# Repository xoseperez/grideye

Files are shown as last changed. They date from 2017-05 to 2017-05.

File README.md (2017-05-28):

# GridEye Camera

This is a 8x8 pixels IR camera based on the **Panasonic AMG88XX GridEye** sensors.
It uses a **WS2812 8x8 matrix** as camera display, an **128x32 uOLED display** for data and
a **Moteino** board with an ATMega328P microcontroller as controller.
It is powered by a **LiPo battery** connected to a **TP4056 based LiPO charger**.
There is also a **Pololu Adjustable Boost Regulator 2.5-9.5V** to power the LED matrix.

The AMG8833 is an 8x8 IR sensor by Panasonic with an I2C interface that reports concact-less temperature values from -20 to 80 celsius with a 2.5C accuracy and 0.25C resolution. It has a field view of ~60º and a max detection distance of 5 meters.

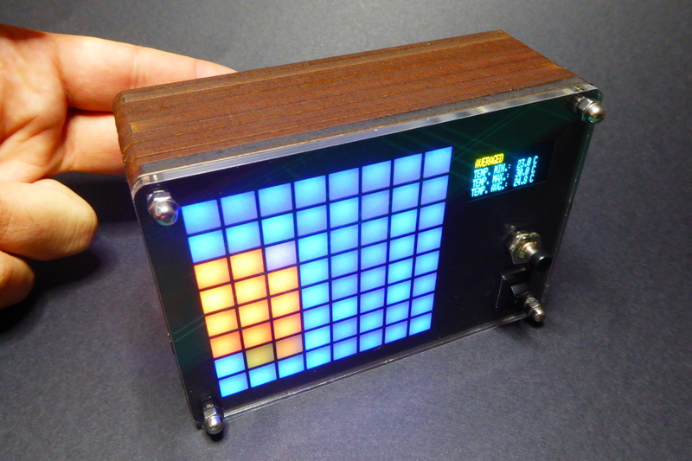
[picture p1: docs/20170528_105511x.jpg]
GridEye Camera


This is part of my "Slices" project, basically a sliced laser cut series of enclosures to house electronic projects.

## Hardware

### The electronics

The project relies on different discreet modules wired together. All the components (or compatible alternatives) are widely available. Only the AMG88XX board is custom made. Check the "amg8833" fordel in this repo for the Eagle files of the board.

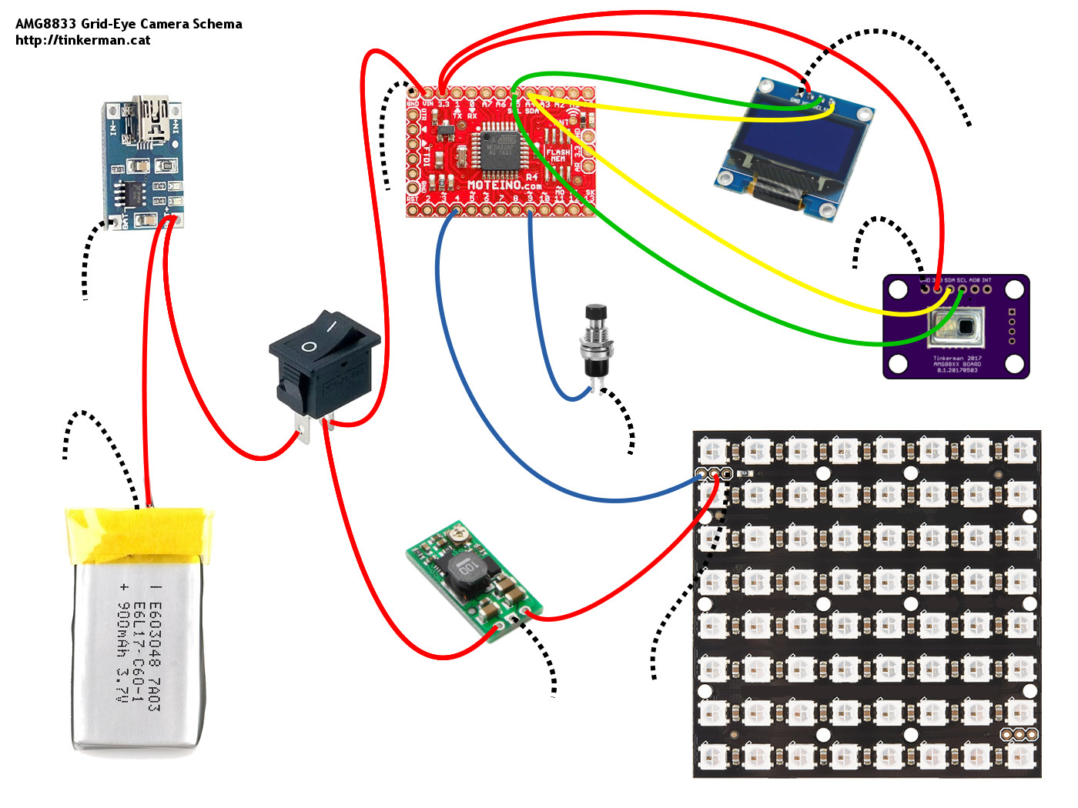
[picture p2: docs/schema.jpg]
GridEye Camera Schema Drawing


All the dotted black lines in the drawing are connected together.

### The housing

The housing has been created using OpenSCAD and inspired by Pimoroni  PiBow enclosures for the RaspBerry Pi. I've been using this same technique lately on different project and I call them all under a common name: "Project Slices".

The enclosure is based on layers or "slices" of different materials.

* Transparent acrylic front-face
* Black cardboard mask
* White paper diffusor
* 4mm MDF grid that houses each LED in its own cubicle
* 2.5mm MDF cast for the LED matrix PCB
* 2.5mm MDF as support for the matrix PCB and uOLED board
* several (5) 4mm MDF hollow layers to house the electronics
* 2.5mm MDF as support for the AMG88XX board
* 4mm MDF hollow layers to house the AMG88XX board
* 2.5mm MDF as a back pane with a hole for the IR sensor

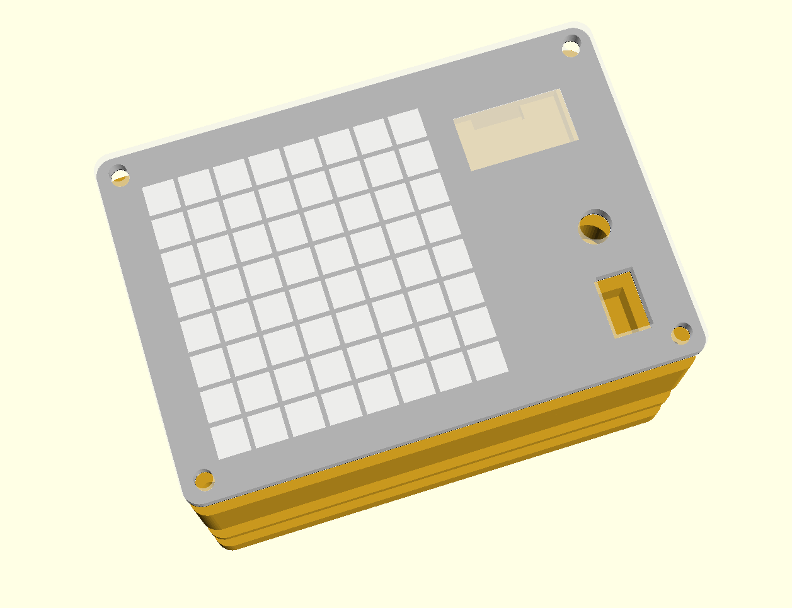
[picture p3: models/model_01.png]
GridEye Camera Housing 1


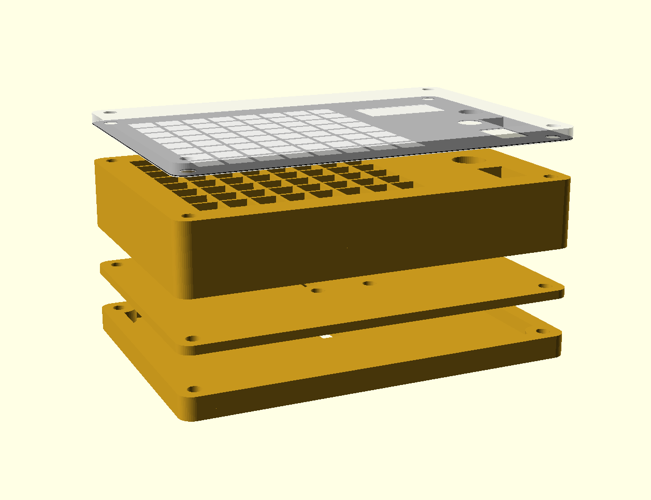
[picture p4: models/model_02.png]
GridEye Camera Housing 2


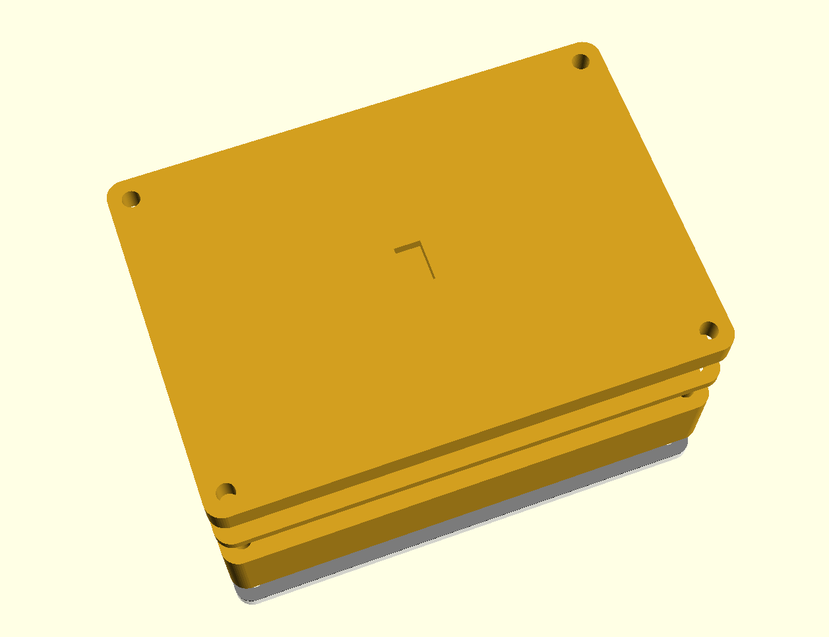
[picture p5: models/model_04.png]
GridEye Camera Housing 3


## Firmware

The project is ready to be build using [PlatformIO](http://www.platformio.org).
Please refer to their web page for instructions on how to install the builder.
Once installed:

```bash
> cd code
> platformio run
> platformio run --target upload
```

Library dependencies are automatically managed via PlatformIO Library Manager.

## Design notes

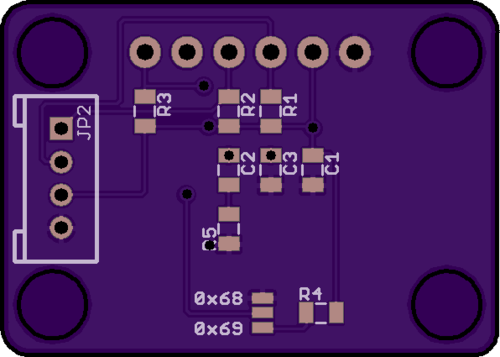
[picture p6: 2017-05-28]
amg8833/amg88xx-v0.1.20170503-render-back.png

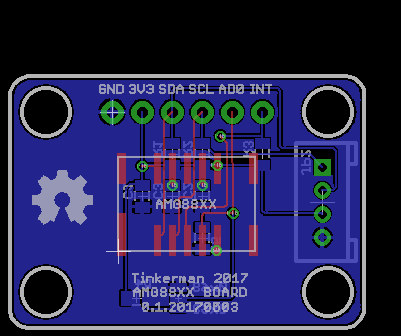
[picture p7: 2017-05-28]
amg8833/amg88xx-v0.1.20170503-board.png

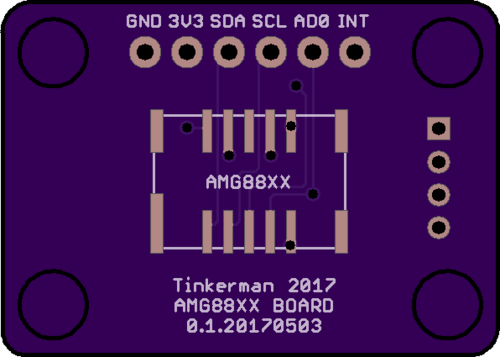
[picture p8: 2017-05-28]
amg8833/amg88xx-v0.1.20170503-render-front.png

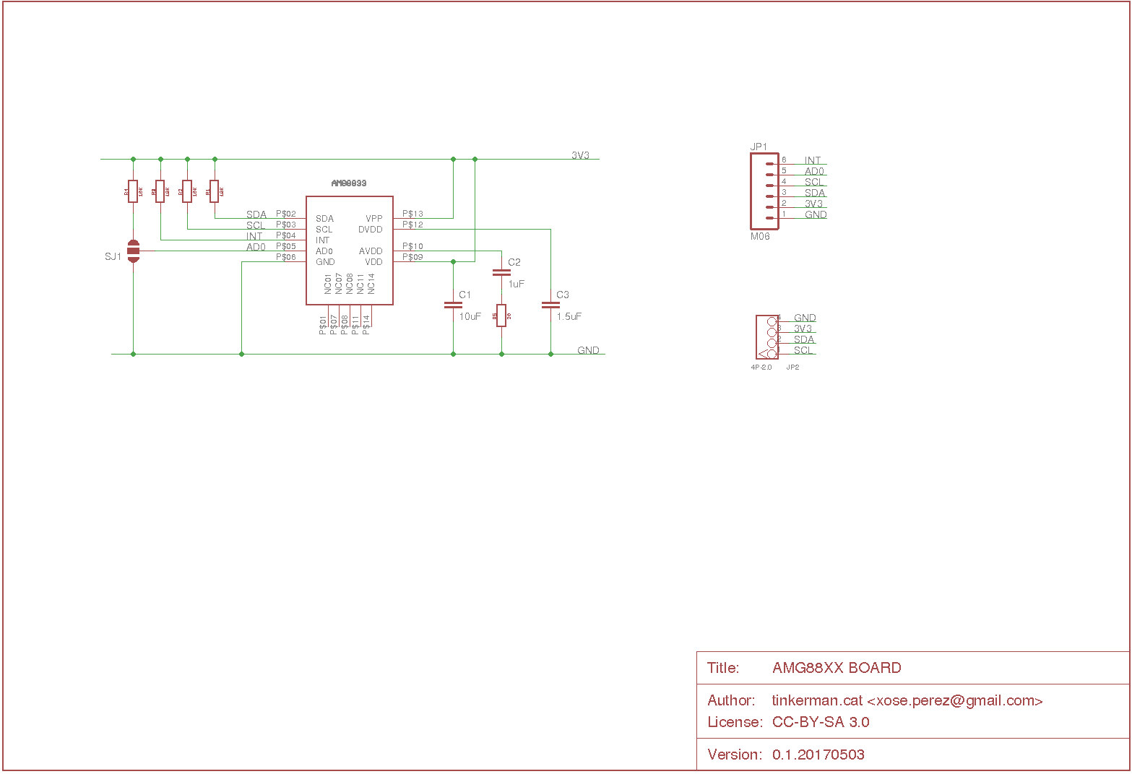
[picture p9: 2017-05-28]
amg8833/amg88xx-v0.1.20170503-schema.png

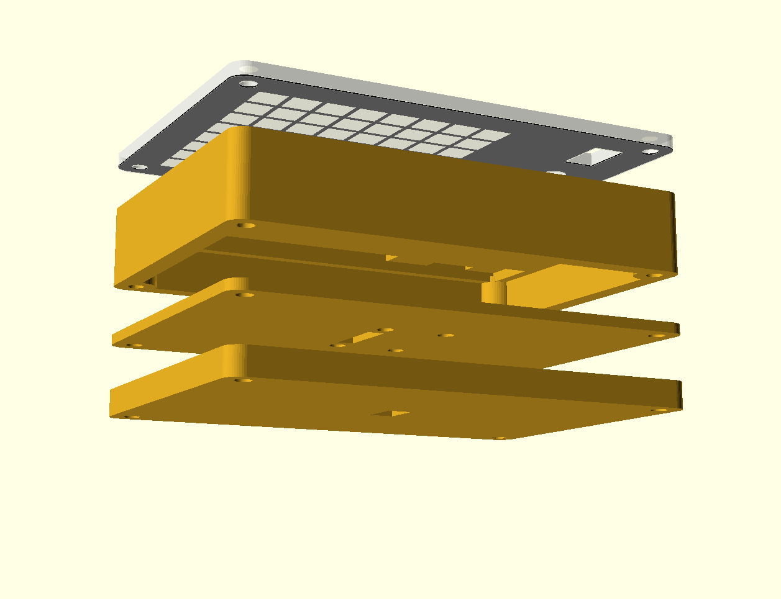
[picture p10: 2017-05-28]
models/model_03.png

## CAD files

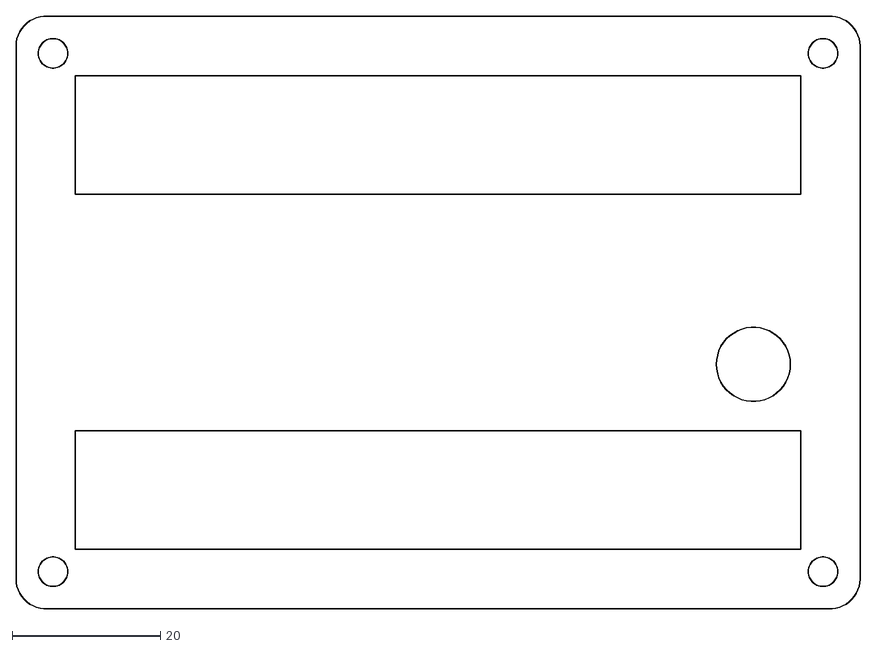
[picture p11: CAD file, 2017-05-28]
models/layers/06 - support.dxf
114.0 x 80.0

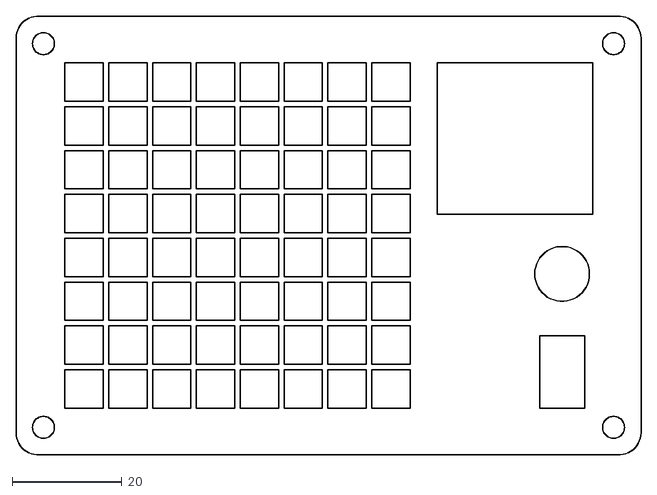
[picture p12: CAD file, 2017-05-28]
models/layers/04 - grid.dxf
114.0 x 80.0

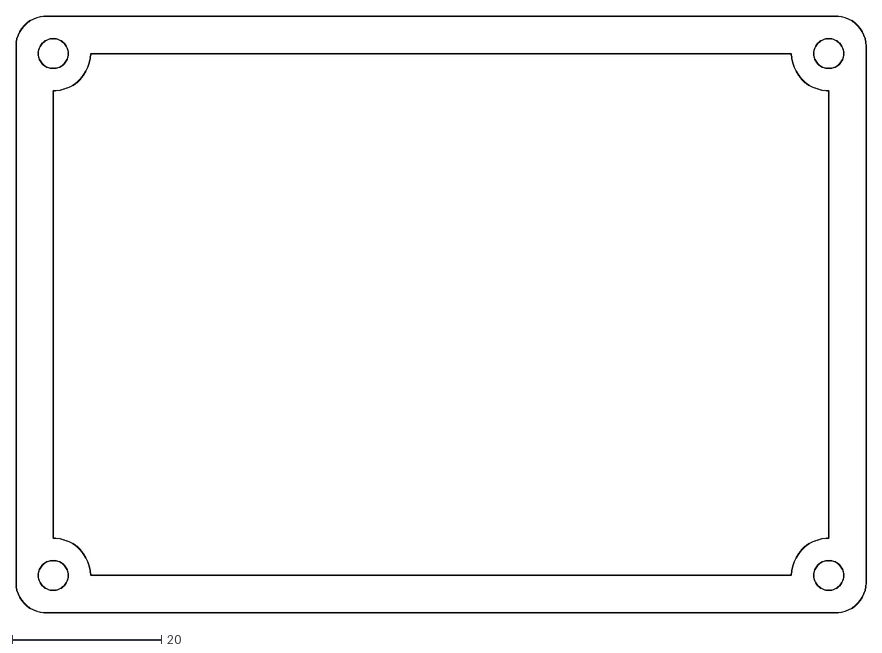
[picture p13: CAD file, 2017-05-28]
models/layers/07 - hollow.dxf
114.0 x 80.0

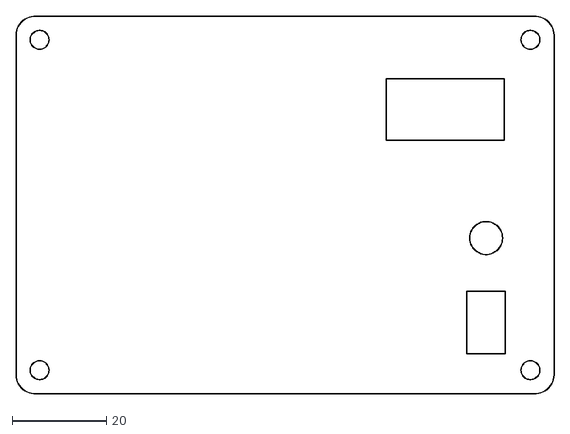
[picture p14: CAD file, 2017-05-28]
models/layers/03 - diffusor.dxf
114.0 x 80.0

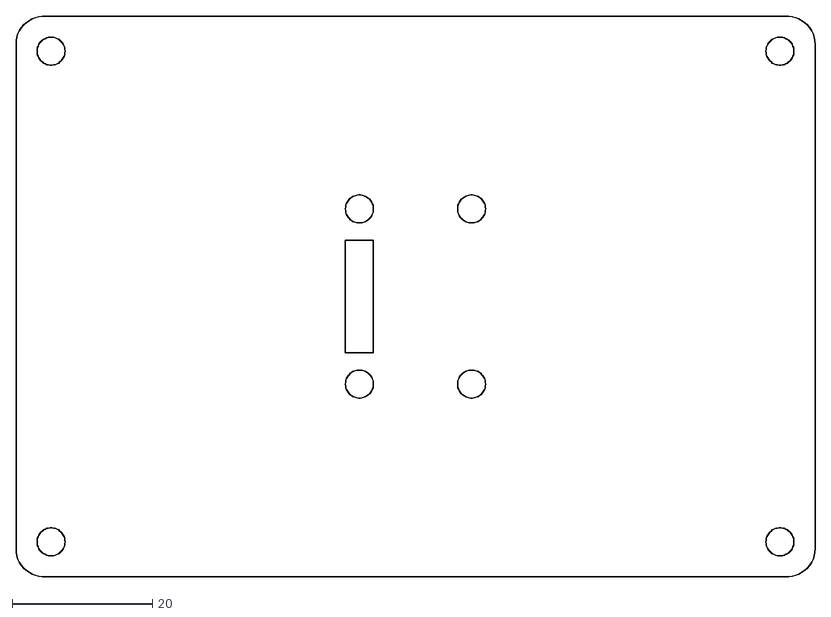
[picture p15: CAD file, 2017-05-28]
models/layers/08 - middle.dxf
114.0 x 80.0

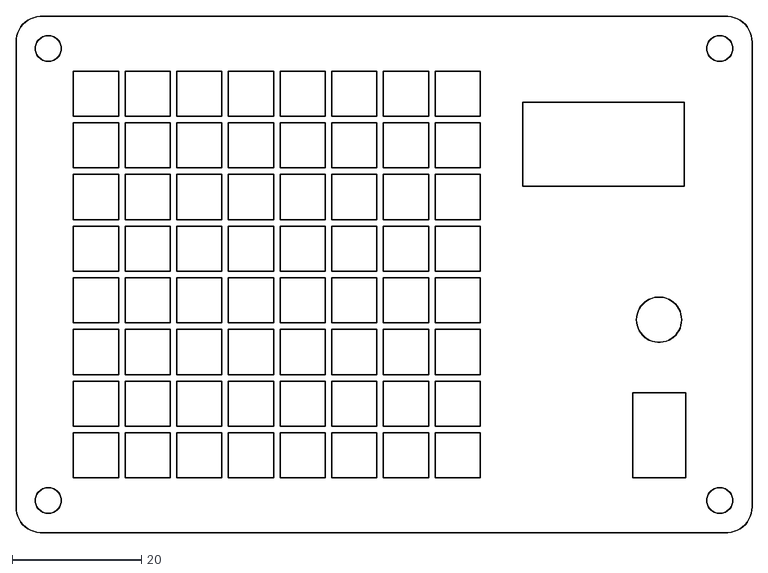
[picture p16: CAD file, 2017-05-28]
models/layers/02 - mask.dxf
114.0 x 80.0

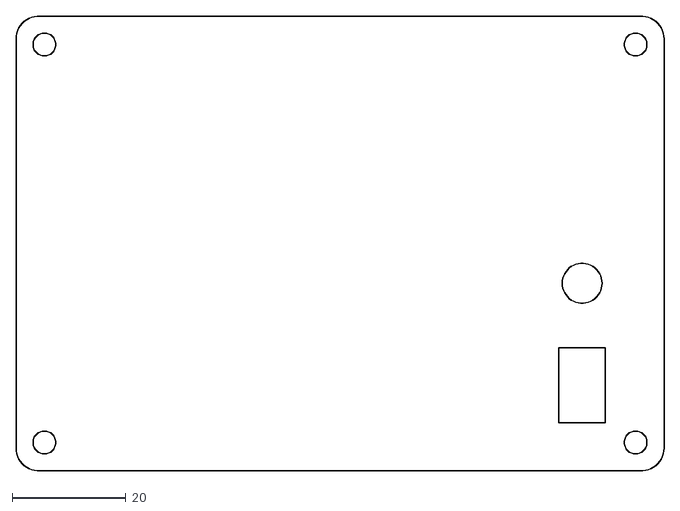
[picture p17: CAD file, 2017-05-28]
models/layers/01 - front.dxf
114.0 x 80.0

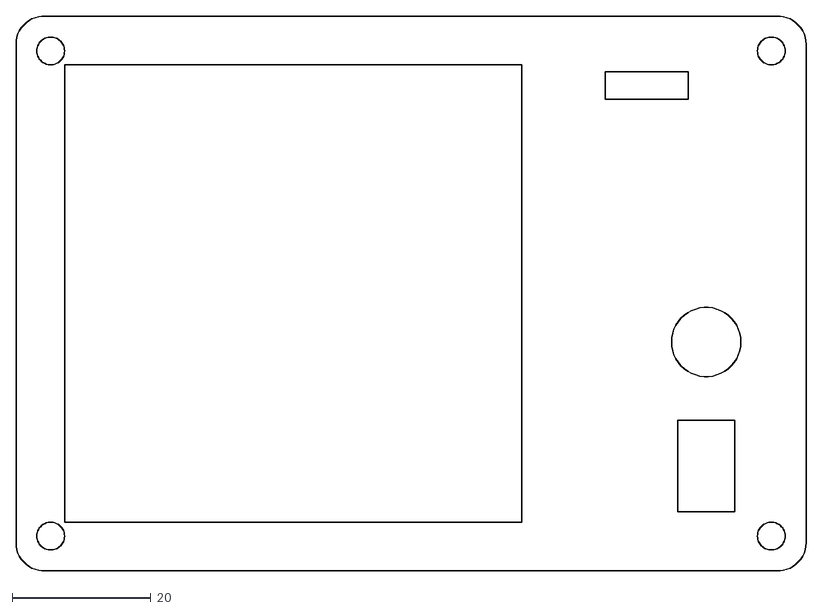
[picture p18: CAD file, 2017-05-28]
models/layers/05 - cast.dxf
114.0 x 80.0

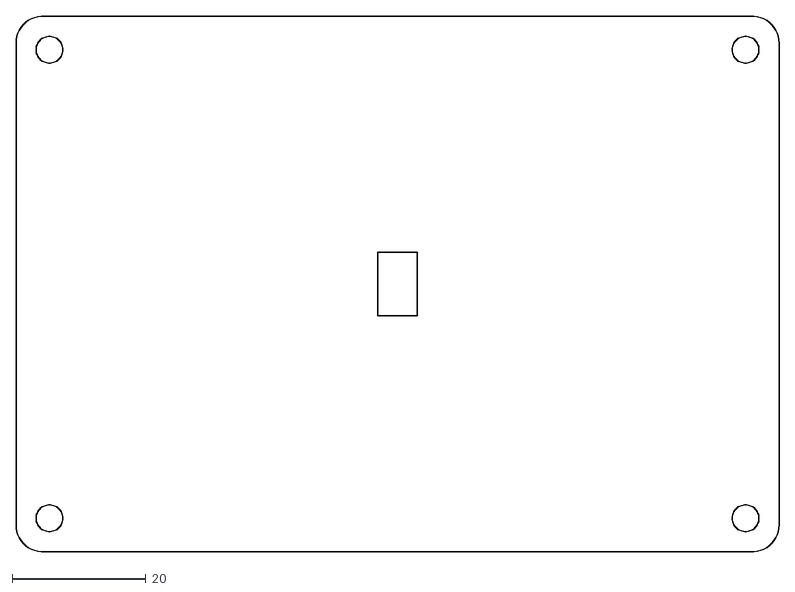
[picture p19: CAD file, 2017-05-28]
models/layers/09 - back.dxf
114.0 x 80.0

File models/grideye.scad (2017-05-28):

//-----------------------------------
// Layers to render
//-----------------------------------

//layer_front(); 
//layer_mask();
//layer_diffusor();
//layer_grid();
//layer_cast();
//layer_support();
//layer_hollow();
//layer_middle();
//layer_back(0,0);

translate([0,0,20]) {
    %translate([0,0,15.1]) color("white",0.5) linear_extrude(3) layer_front();
    translate([0,0,14.9]) color("black",1.0) linear_extrude(0.1) layer_mask();
    translate([0,0,14.7]) color("white",0.5) linear_extrude(0.1) layer_diffusor();
    color("Goldenrod")  {
        linear_extrude(4) layer_grid();
        translate([0,0,-2.5]) linear_extrude(2.5) layer_cast();
        translate([0,0,-5]) linear_extrude(2.5) layer_support();
        translate([0,0,-7.5]) linear_extrude(4) layer_hollow();
        translate([0,0,-11.5]) linear_extrude(4) layer_hollow();
        translate([0,0,-15.5]) linear_extrude(4) layer_hollow();

        translate([0,0,-30]) linear_extrude(2.5) layer_middle();
       
        translate([0,0,-45]) linear_extrude(4) layer_hollow();
        translate([0,0,-47.5]) linear_extrude(2.5) layer_back(0,0);

    }
}

//-----------------------------------
// Configuration
//-----------------------------------

// Model size
model_width=114;
model_height=80;

// Grid config
grid_size = 8;
grid_step = 8;
grid_shift = 0.4;
grid_wall = 1;

// Height of the grid (widt of the wood)
wood_width=4;

// Holes radius (half of metric: M3, M4...)
hole_size=2; // M4

// Hole distance to edge
hole_distance=5;

// Minkowski radius
chamfer_size=4;

//-----------------------------------
// DO NOT TOUCH BELOW THIS LINE
//-----------------------------------

//-----------------------------------
// Components
//-----------------------------------

module hole() {
    translate([
        model_width/2-hole_distance,
        model_height/2-hole_distance,
        0
    ]) circle(hole_size, center=true, $fn=50);
}

module hole_ring() {
    translate([
        model_width/2-hole_distance,
        model_height/2-hole_distance,
        0
    ]) circle(5, center=true, $fn=50);
}

module base() {
    
    difference() {
        
        // Shape
        minkowski() {
            square([
                model_width-2*chamfer_size,
                model_height-2*chamfer_size
           ], true);
            circle(chamfer_size, $fn=50);
        }

        // Holes
        mirror([0,0,0]) hole();
        mirror([1,0,0]) hole();
        mirror([0,1,0]) {
            mirror([0,0,0]) hole();
            mirror([1,0,0]) hole();
        }

    }
}

module led_matrix_negative(type) {

    translate([
        grid_shift-grid_size*grid_step/2,
        -grid_size*grid_step/2
    ])
    for (x=[0:grid_size-1]) {
        for (y=[0:grid_size-1]) {
            translate([
                x*grid_step+grid_wall/2,
                y*grid_step+grid_wall/2,0
            ]) {
                square(grid_step-grid_wall);
            }
        }
    }

}

module switch() {
    square([8.2, 13.2], true);
}

module socket_hole(inside=0) {
    circle(inside ? 16/2 : 11.4/2, $fn=50);
}
module oled(type=0) {
    if (type==0) {
        square([28.4,27.6], true);
    } 
    if (type==1) {
        translate([0,27.6/2-1.5]) square([12,4], true);
    }
    if (type==2) {
        //translate([0,2.5]) square([27,15], true);
        translate([0,2.5]) square([25,13], true);
    }
}

module grid_eye(type) {
    
    // holes
    if (type==0) {
        translate([3-22/2, 3-31/2]) circle(2, $fn=50);
        translate([22/2-3, 3-31/2]) circle(2, $fn=50);
        translate([3-22/2, 31/2-3]) circle(2, $fn=50);
        translate([22/2-3, 31/2-3]) circle(2, $fn=50);
    } 
    
    // sensor
    if (type==1) {
        square([5.9,9.5], true);
    }
    
    // pcb
    if (type==2) {
        square([22,31], true);
    }
    
    // connectors
    if (type==3) {
        translate([3-22/2,0]) square([4,16], true);
    }
    
}

module button(type=0) {
    if (type==0) {
        circle(7/2, $fn=50);
    }
    if (type==1) {
        circle(10/2, $fn=50);
    }
}


//-----------------------------------
// Layers
//-----------------------------------

module layer_front() {
    difference() {
        base();
        //translate([27.0,-24.9]) socket_hole(0);
        translate([42.6,-24.9]) switch();
        translate([42.6,-7]) button(0);
    }
}

module layer_grid() {

    difference() {
        base();
        translate([-(model_width-model_height)/2,0])
            led_matrix_negative(1);
        translate([34,17.7]) oled(0);
        //translate([27.0,-24.9]) socket_hole(1);
        translate([42.6,-24.9]) switch();
        translate([42.6,-7]) button(1);
    }

}

module layer_mask() {

    difference() {
        base();
        translate([-(model_width-model_height)/2,0])
            led_matrix_negative(1);
        translate([34,17.7]) oled(2);
        //translate([27.0,-24.9]) socket_hole(0);
        translate([42.6,-24.9]) switch();
        translate([42.6,-7]) button(0);
    }

}

module layer_diffusor() {

    difference() {
        base();
        translate([34,17.7]) oled(2);
        //translate([27.0,-24.9]) socket_hole(0);
        translate([42.6,-24.9]) switch();
        translate([42.6,-7]) button(0);
    }

}

module layer_cast() {

    difference() {
        base();
        translate([-(model_width-model_height)/2,0])
            square(grid_size*grid_step+2, true);
        //translate([27.0,-24.9]) socket_hole(1);
        translate([42.6,-24.9]) switch();
        translate([34,17.7]) oled(1);
        translate([42.6,-7]) button(1);
    }

}

module layer_support() {

    difference() {
        base();
        translate([0, grid_step*(grid_size/2-1)])
            square([model_width-2*grid_size, grid_step*2], true);
        translate([0, -grid_step*(grid_size/2-1)])
            square([model_width-2*grid_size, grid_step*2], true);
        //translate([27.0,-24.9]) socket_hole(1);
        translate([42.6,-24.9]) switch();
        translate([42.6,-7]) button(1);
    }

}

module layer_hollow() {
    difference() {
        base();
        difference() {
            square([
                model_width-2*hole_distance,
                model_height-2*hole_distance
            ],true);
            mirror([0,0,0]) hole_ring();
            mirror([1,0,0]) hole_ring();
            mirror([0,1,0]) {
                mirror([0,0,0]) hole_ring();
                mirror([1,0,0]) hole_ring();
            }
        }
    }
}

module layer_middle() {
    difference() {
        base();
        grid_eye(0);
        grid_eye(3);
    }
}


module layer_back(transparent=0, holes=0) {
    difference() {
        base();
        if (holes) grid_eye(0);
        if (!transparent) grid_eye(1);
    }
}

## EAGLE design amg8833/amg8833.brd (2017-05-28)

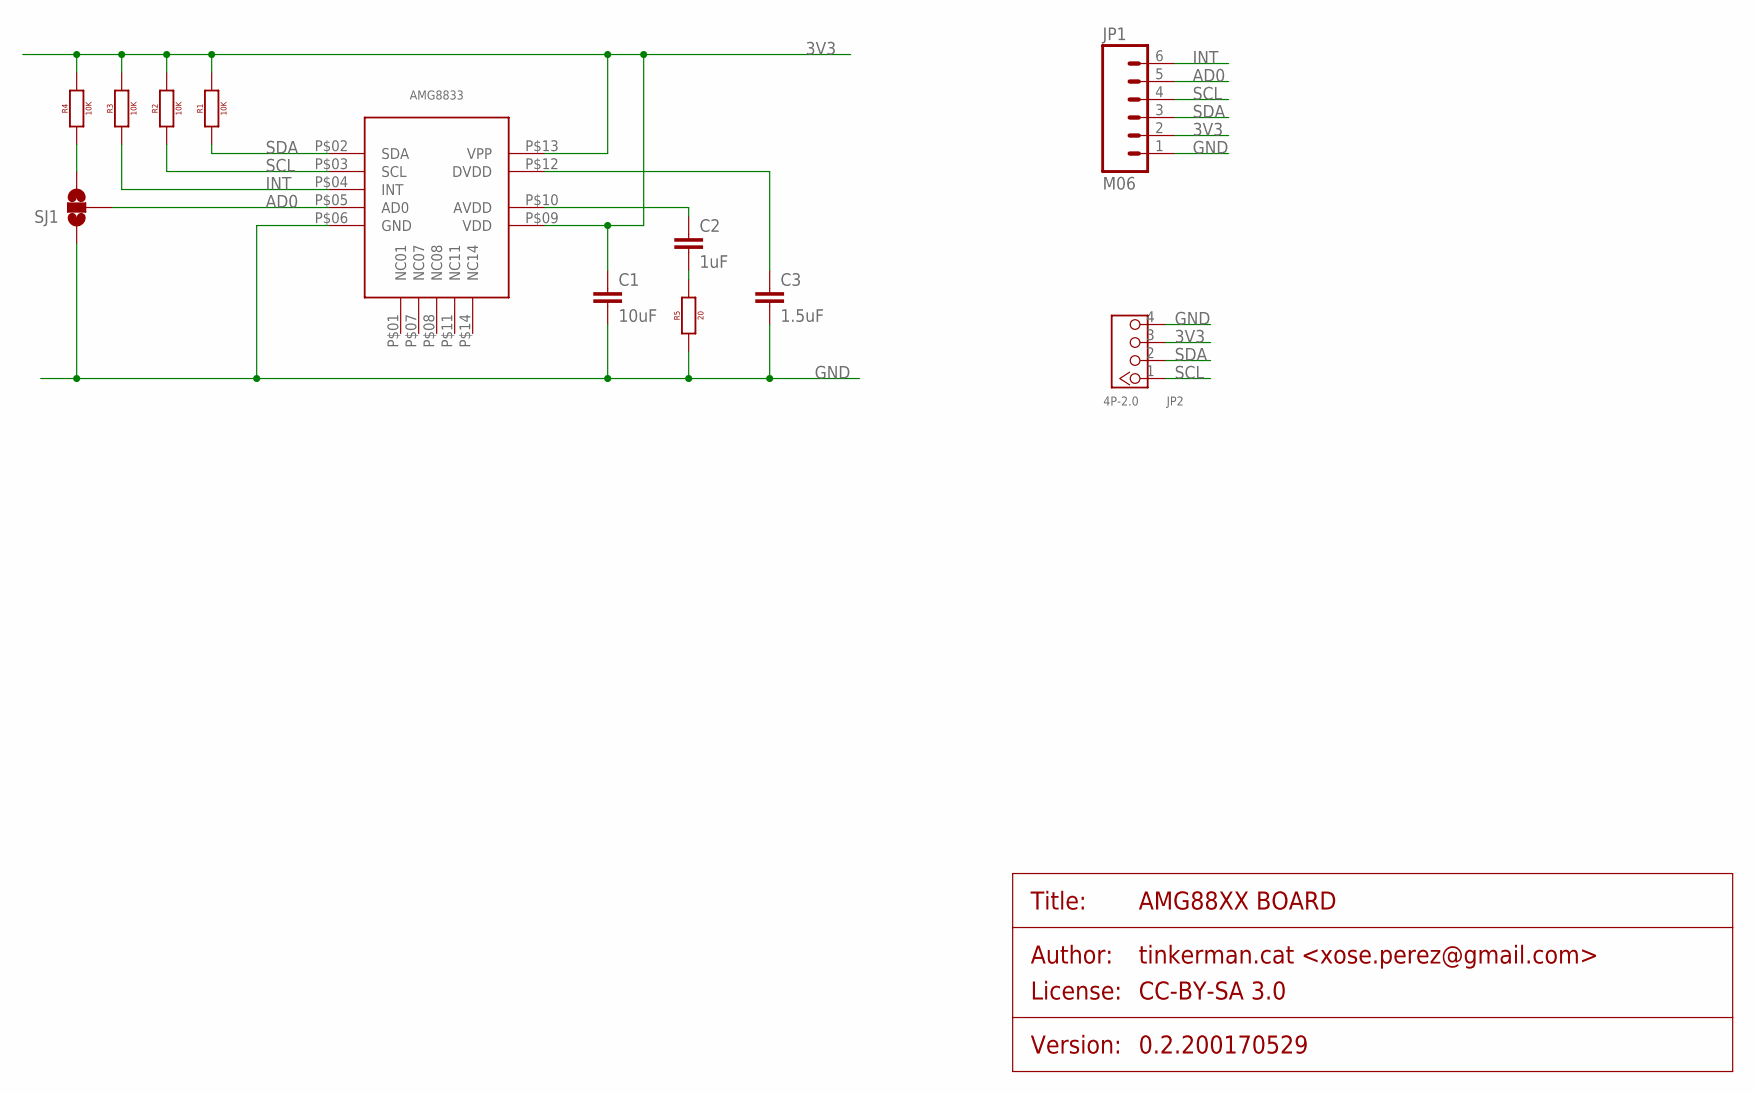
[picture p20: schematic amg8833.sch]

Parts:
AMG8833: AMG88XX
C1: 10uF; 0805
C2: 1uF; 0805
C3: 1.5uF; 0805
JP1: M06; 1X06_NO_SILK
JP2: 4P-2.0; HW4-2.0
R1, R2, R3, R4: 10K; 0805
R5: 20; 0805
SJ1: SOLDERJUMPER_2WAYS; SJ_3

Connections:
3V3: AMG8833.P$09 (VDD), AMG8833.P$13 (VPP), C1.1, JP1.2, JP2.3, R1.2, R2.2, R3.2, R4.2
AD0: AMG8833.P$05 (AD0), JP1.5, SJ1.2
GND: AMG8833.P$06 (GND), C1.2, C3.2, JP1.1, JP2.4, R5.1, SJ1.1
INT: AMG8833.P$04 (INT), JP1.6, R3.1
unnamed: R4.1, SJ1.3
unnamed: C2.2, R5.2
unnamed: AMG8833.P$12 (DVDD), C3.1
unnamed: AMG8833.P$10 (AVDD), C2.1
SCL: AMG8833.P$03 (SCL), JP1.4, JP2.1, R2.1
SDA: AMG8833.P$02 (SDA), JP1.3, JP2.2, R1.1

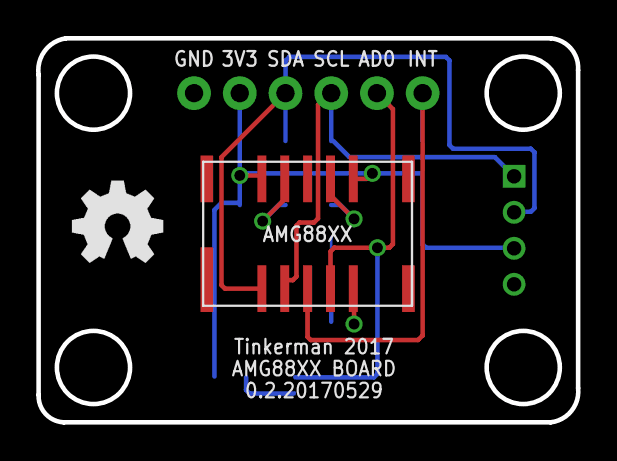
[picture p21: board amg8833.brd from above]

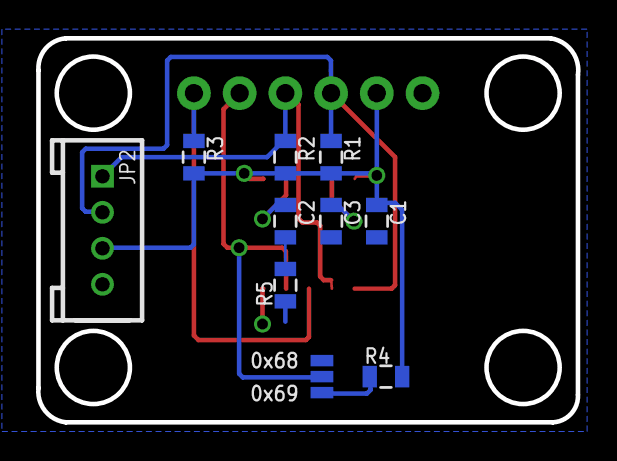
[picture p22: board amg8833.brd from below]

Board: 2 copper layers, 30.0 x 21.3 mm, 12 parts (10 on the bottom side), 10 nets.

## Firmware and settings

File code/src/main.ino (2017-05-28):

#include "config.h"
#include <Wire.h>
#include <SPI.h>
#include <FastLED.h>
#include <MemoryFree.h>

// -----------------------------------------------------------------------------
// HARDWARE
// -----------------------------------------------------------------------------

void i2c_scanner() {

    byte error, address;
    int nDevices;

    nDevices = 0;
    for(address = 1; address < 127; address++ ) {

        // The i2c_scanner uses the return value of
        // the Write.endTransmisstion to see if
        // a device did acknowledge to the address.
        Wire.beginTransmission(address);
        error = Wire.endTransmission();

        if (error == 0) {
            SERIAL_PORT.print(F("[I2C] Device found at address 0x"));
            SERIAL_PORT.println(address, HEX);
            nDevices++;
        } else if (error==4) {
            SERIAL_PORT.print(F("[I2C] Unknown error at address 0x"));
            SERIAL_PORT.println(address, HEX);
        }
    }

    if (nDevices == 0) SERIAL_PORT.println(F("[I2C] No devices found"));

}

void freeMem() {
    SERIAL_PORT.print(F("[MAIN] Free memory: "));
    SERIAL_PORT.println(freeMemory());
}

void hardwareSetup() {

    SERIAL_PORT.begin(SERIAL_BAUDRATE);
    SERIAL_PORT.println("[MAIN] Starting");
    freeMem();

    Wire.begin();
    i2c_scanner();

    powerSetup();
    amgSetup();
    buttonSetup();
    #if ENABLE_MATRIX
        matrixSetup();
    #endif
    displaySetup();

}

void writeByte(unsigned char address, unsigned char reg, unsigned char data) {
    Wire.beginTransmission(address);
    Wire.write(reg);
    Wire.write(data);
    Wire.endTransmission();
}

unsigned char readByte(unsigned char address, unsigned char reg) {

    unsigned char response = 0;

    Wire.beginTransmission(address);
    Wire.write(reg);
    Wire.endTransmission();

    Wire.requestFrom(address, (unsigned char) 1);
    if (1 == Wire.available()) {
        response = Wire.read();
    }

    return response;

}

void readBytes(unsigned char address, unsigned char reg, unsigned char count, unsigned char * dest) {

    Wire.beginTransmission(address);
    Wire.write(reg);
    Wire.endTransmission();

    Wire.requestFrom(address, count);

    unsigned char position = 0;
    while (position < count) {
        dest[position++] = Wire.read();
    }

}

// -----------------------------------------------------------------------------
// MAIN
// -----------------------------------------------------------------------------

void setup() {
    hardwareSetup();
}

void loop() {
    buttonLoop();
    amgLoop();
    displayLoop();
}

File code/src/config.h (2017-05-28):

//------------------------------------------------------------------------------
// GENERAL
//------------------------------------------------------------------------------

#define SERIAL_PORT                 Serial
#define SERIAL_BAUDRATE             115200

#define ENABLE_MATRIX               1

//--------------------------------------------------------------------------------
// STATES
//--------------------------------------------------------------------------------

#define STATE_NORMAL                0
#define STATE_PATTERN               1
#define STATE_BRIGHTNESS            2
#define STATE_COUNT                 3

//--------------------------------------------------------------------------------
// AMG8833
//--------------------------------------------------------------------------------

// Max refresh update for the AMG8833 is 10Hz as per datasheet (100ms)
#define AMG8833_UPDATE_INTERVAL     100

//--------------------------------------------------------------------------------
// POWER
//--------------------------------------------------------------------------------

#define POWER_MONITOR_PIN           A0
#define POWER_MONITOR_RATIO         2.0

//--------------------------------------------------------------------------------
// MATRIX
//--------------------------------------------------------------------------------

#define MATRIX_PIN                  4
#define MATRIX_WIDTH                8
#define MATRIX_HEIGHT               8
#define MATRIX_CHIPSET              WS2812B
#define MATRIX_COLOR_ORDER          GRB
#define MATRIX_LEDS                 (MATRIX_WIDTH * MATRIX_HEIGHT)
#define MATRIX_DEFAULT_BRIGHTNESS   0

const char brightness_low[] PROGMEM = "LOW";
const char brightness_medium[] PROGMEM = "MEDIUM";
const char brightness_high[] PROGMEM = "HIGH";
const char * const BrigthnessName[] PROGMEM = {
    brightness_low,
    brightness_medium,
    brightness_high
};


//--------------------------------------------------------------------------------
// BUTTON
//--------------------------------------------------------------------------------

#define BUTTON_PIN                  9
#define BUTTON_PULLUP               1
#define BUTTON_DEBOUNCE_MS          20
#define BUTTON_DOUBLE_CLICK_MS      300
#define BUTTON_LONG_CLICK_MS        500

//--------------------------------------------------------------------------------
// DISPLAY
//--------------------------------------------------------------------------------

#define DISPLAY_UPDATE_INTERVAL     1000

//--------------------------------------------------------------------------------
// COLOR PATTERNS
//--------------------------------------------------------------------------------

#define PATTERN_AVERAGED            0
#define PATTERN_HUMAN               1
#define PATTERN_COUNT               2

const char pattern_averaged[] PROGMEM = "AVERAGED";
const char pattern_human[] PROGMEM = "HUMAN";
const char * const ColorPatternName[] PROGMEM = {
    pattern_averaged,
    pattern_human
};

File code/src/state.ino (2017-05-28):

/*

STATE MODULE

Copyright (C) 2016-2017 by Xose Pérez <xose dot perez at gmail dot com>

*/

// -----------------------------------------------------------------------------
// STATE
// -----------------------------------------------------------------------------

unsigned char _state = STATE_NORMAL;
unsigned char _pattern = PATTERN_HUMAN;
unsigned char _brightness = 0;

unsigned char getState() {
    return _state;
}

unsigned char getPattern() {
    return _pattern;
}

unsigned char getBrightness() {
    return _brightness;
}

void stateNext() {
    _state = (_state + 1) % STATE_COUNT;
    displayUpdate();
}

void optionNext() {
    if (_state == STATE_PATTERN) {
        _pattern = (_pattern + 1) % PATTERN_COUNT;
    }
    if (_state == STATE_BRIGHTNESS) {
        _brightness = (_brightness + 1) % 3;
        #if ENABLE_MATRIX
        matrixBrightness(_brightness);
        #endif
    }
    displayUpdate();
}

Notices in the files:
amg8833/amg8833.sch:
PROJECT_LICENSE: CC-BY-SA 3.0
